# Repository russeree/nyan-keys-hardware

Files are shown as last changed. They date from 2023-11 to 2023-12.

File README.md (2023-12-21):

# Nyan Keys Hardware Docs v0.8a
Hardware documentation for the Nyan keys keyboard. Mixed licenses everything other than the board files are licensed under Apache-2.0 and board files are licensed under Attribution-NonCommercial-NoDerivatives. 

Made with ❤️ by Portland.HODL - If you like my work please submit PRs and or like/star my repos.

# Links to Firmware and FPGA Bitstream
Nyan Keys has 4 other repositories that go along with the hardware designs listed below
 - [FGPA Bitstream](https://github.com/russeree/nyan-keys-ice40hx4k-bitstream)
 - [STM32 Firmware](https://github.com/russeree/nyan-keys-stm32-firmware)
 - [Web Serial API GUI - hosted](https://russeree.github.io/)
 - [Web Serial API GUI - Source](https://github.com/russeree/nyan-keys-gui)

# Schematics
Schematics are provided as a .pdf file and will up to date with the latest release of Nyan keys hardware.

# Board Files
Board files are located under the board_files directory and were created in KiCad. These are licensed under
Creative Commons Attribution-NonCommercial-NoDerivatives license currently to prevent direct copying and 
manufacturing of the board files for commercial purposes.

Personal use is completely premised for this so if you want to make one for yourself or mod it feel free!

If you would like to avoid the logistics of acquiring the parts and getting a board made. I can fabricate and assemble boards on request. Please just email admin@qrsnap.io. 

# Board Revisions
| Board Version | Notes |
| --- | ----- |
| 0.8a | Prototypes 000, 001 **_USB DP/DM Error_** |
| 0.9a | Initial Release - USB Error Fixed|
| 0.9b | Added DFU Soft Select, All 0402, Tag Connect with clips |

# Layout
<div align="center">
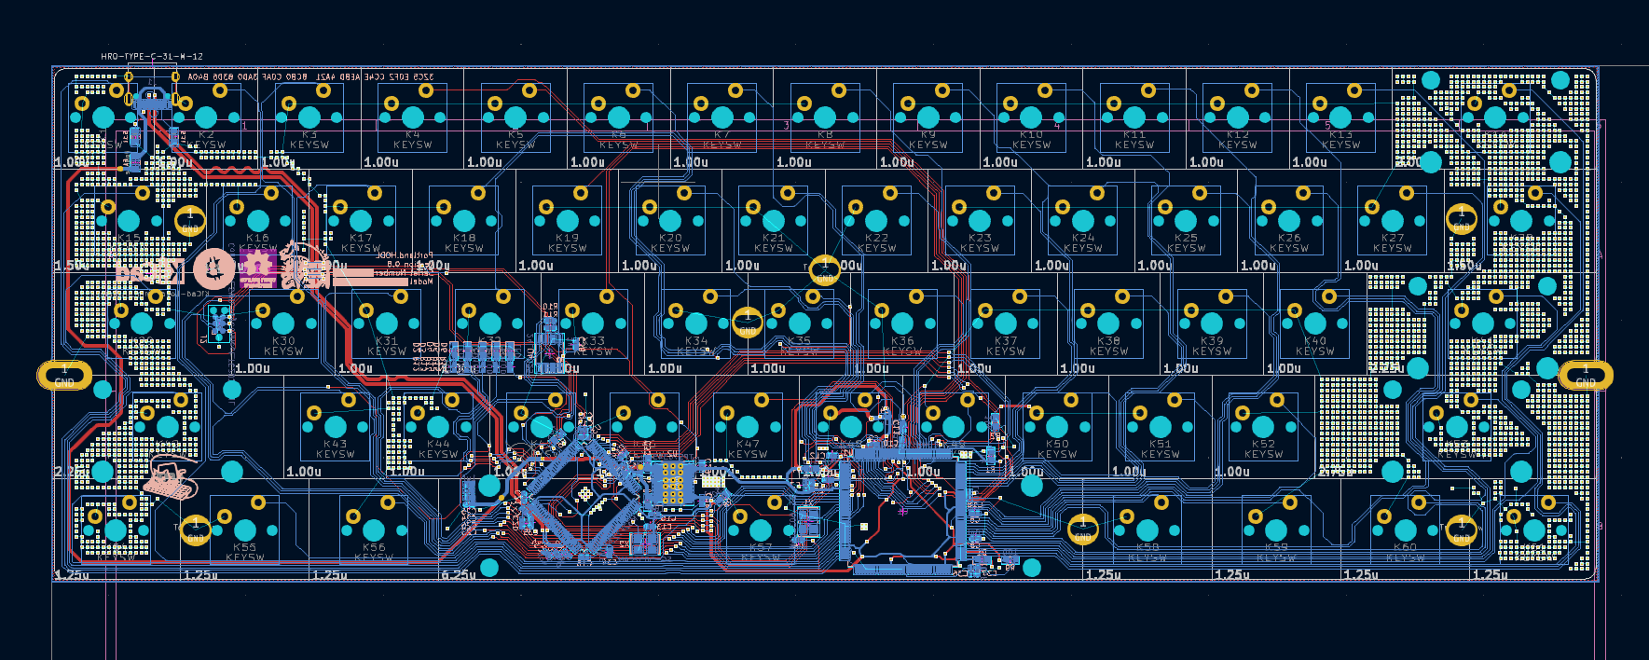
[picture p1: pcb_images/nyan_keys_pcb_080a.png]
    
</div>

<br>

# Finished Photos
<div align="center">
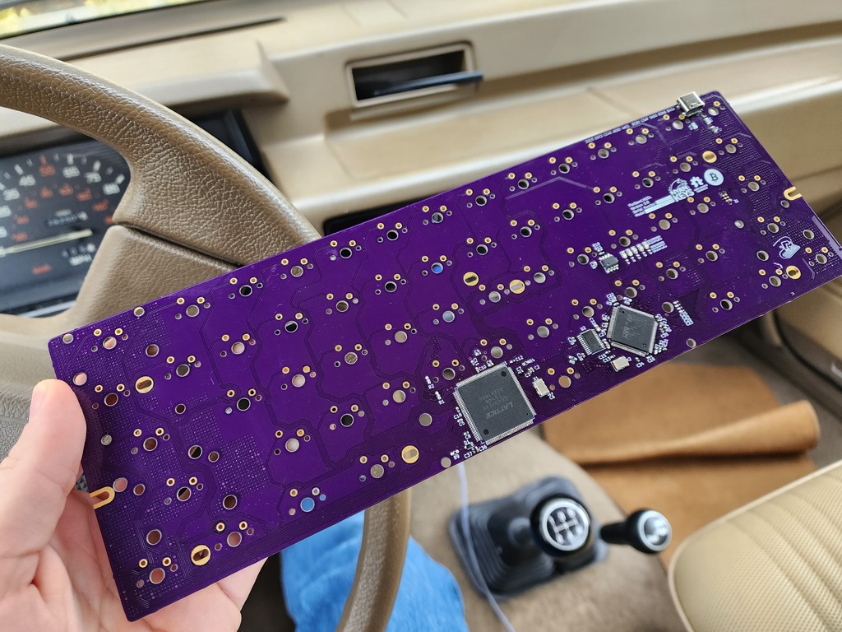
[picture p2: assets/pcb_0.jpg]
    
    <hr>
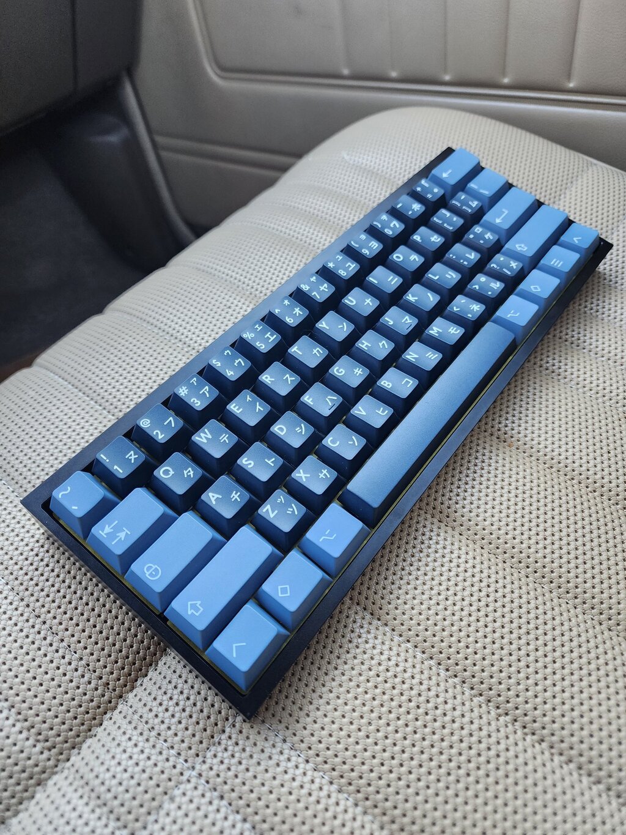
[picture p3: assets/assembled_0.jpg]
    
</div>

# Fabrication
<div align="center">
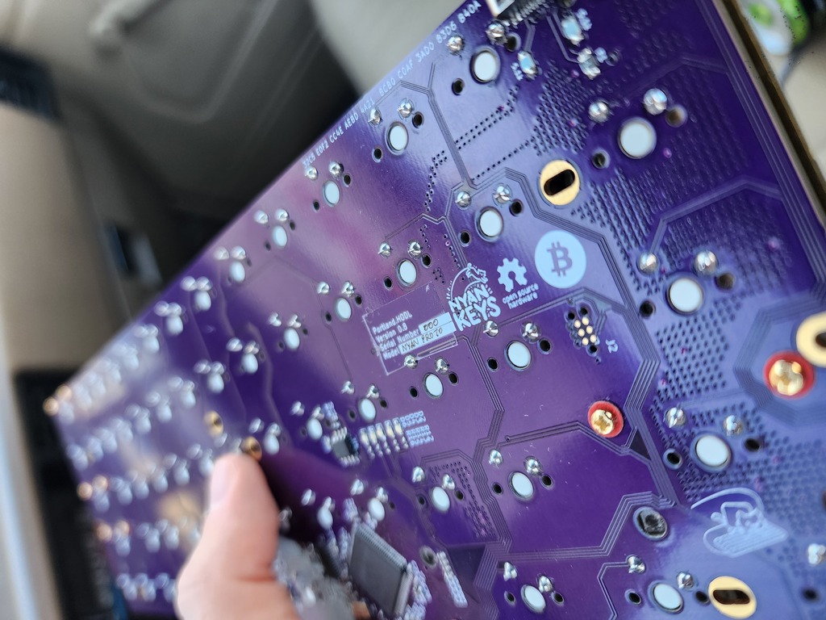
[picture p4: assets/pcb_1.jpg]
    
    <hr>
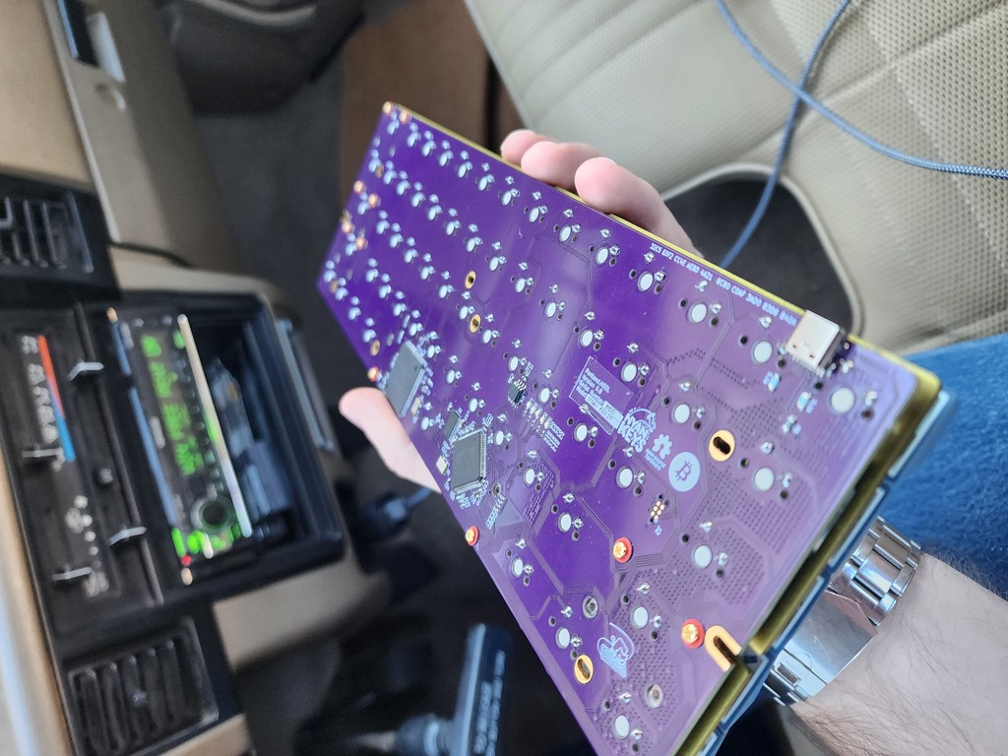
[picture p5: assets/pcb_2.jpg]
    
    <hr>
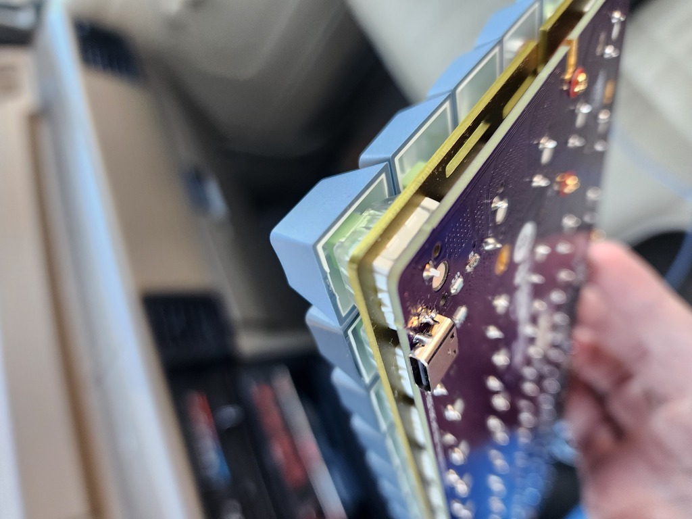
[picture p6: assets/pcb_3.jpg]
    
    <hr>
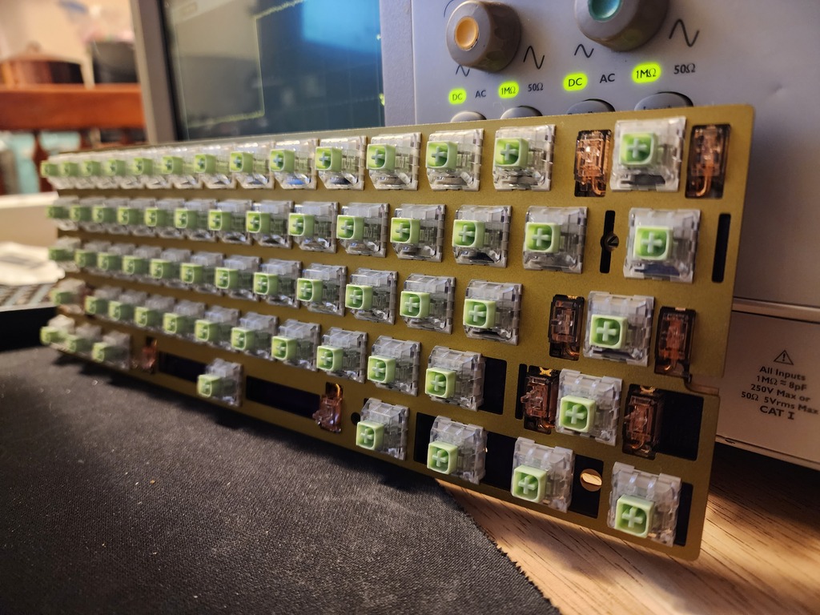
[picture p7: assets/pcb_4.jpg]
    
    <hr>
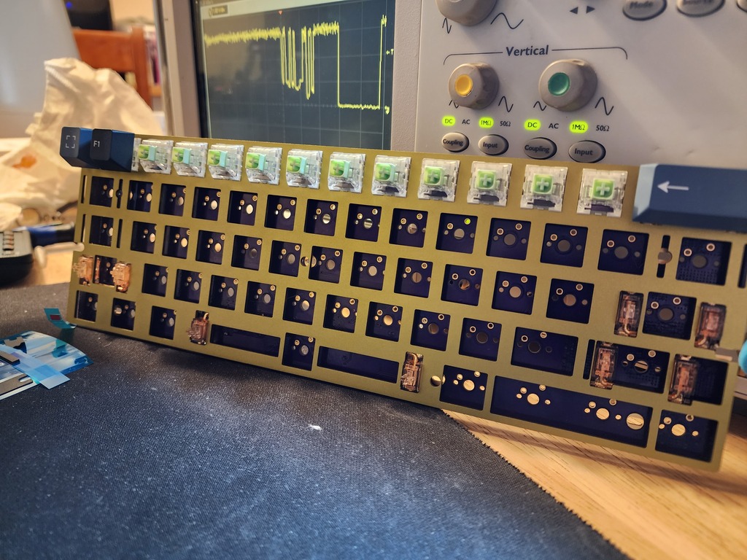
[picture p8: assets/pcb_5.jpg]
    
    <hr>
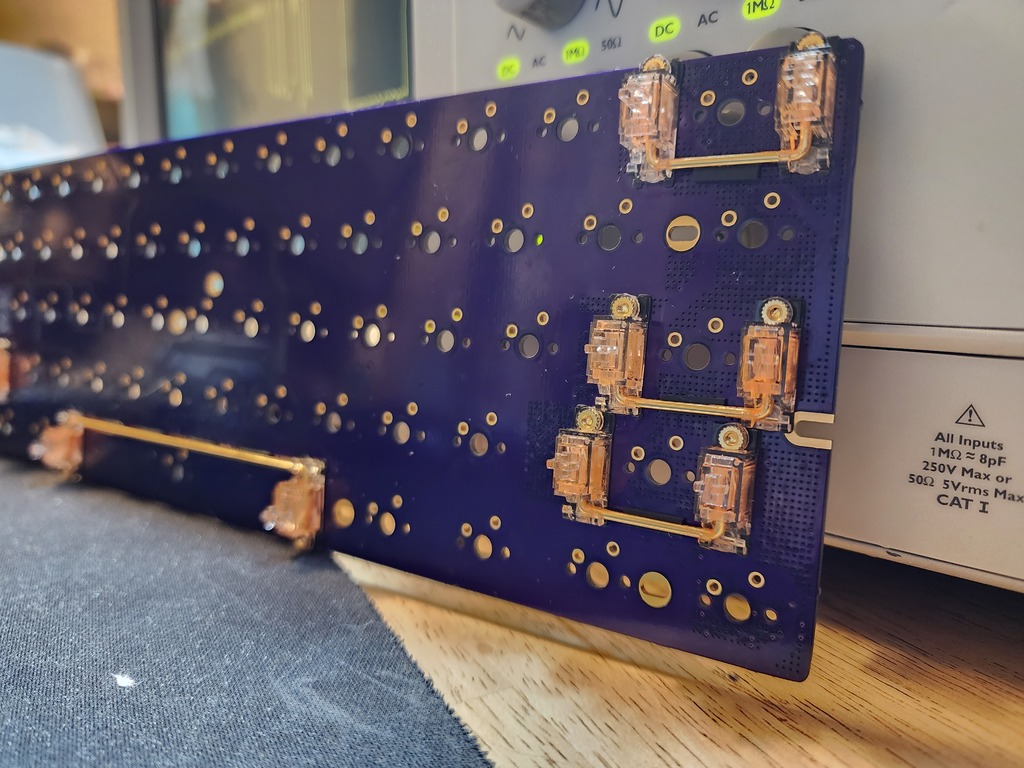
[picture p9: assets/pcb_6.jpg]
    
</div>

<br>

# Assembly
<div align="center">
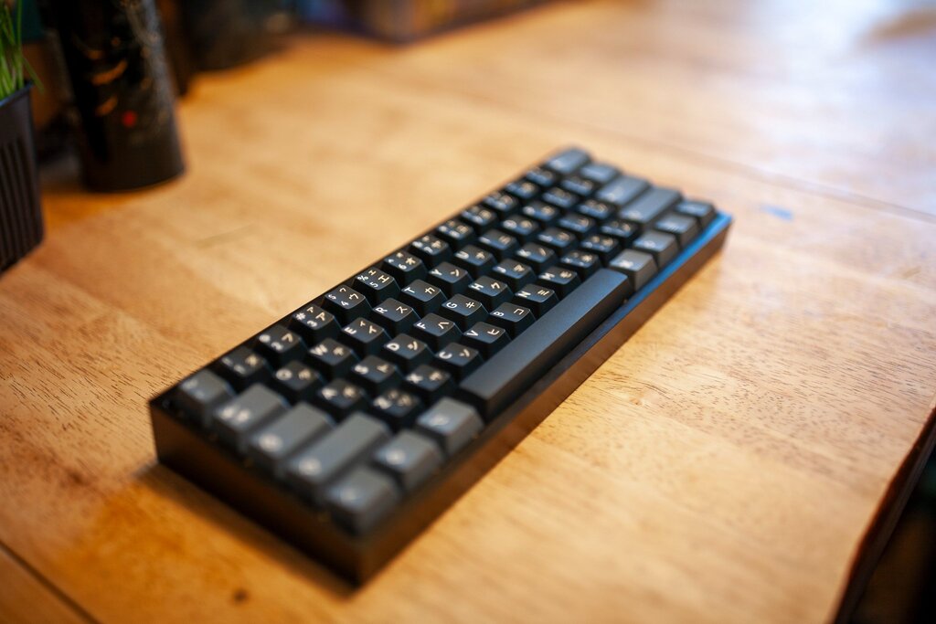
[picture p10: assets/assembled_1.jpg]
    
    <hr>
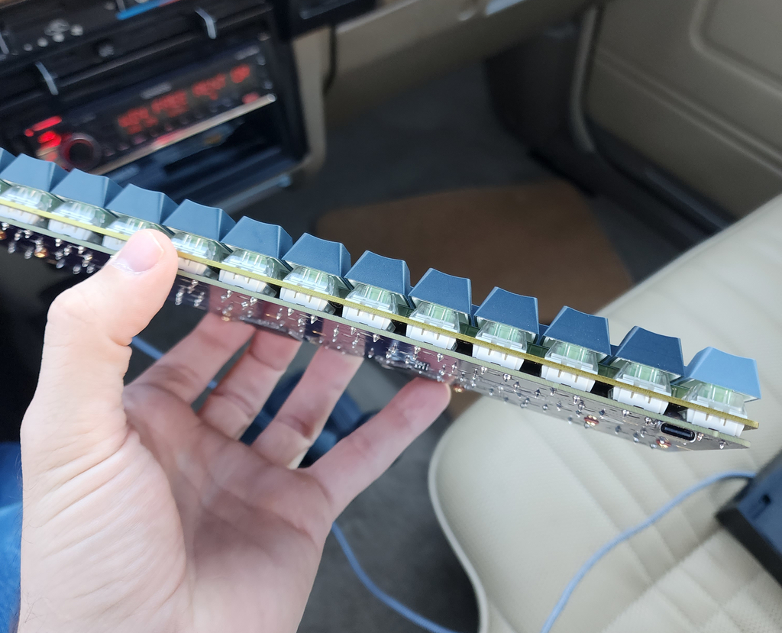
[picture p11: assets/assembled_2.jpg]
    
    <hr>
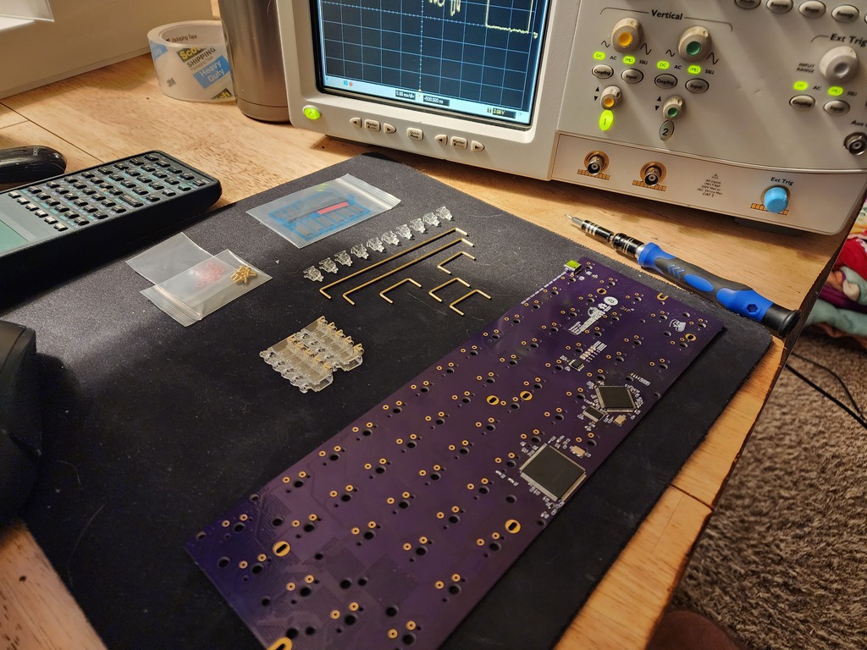
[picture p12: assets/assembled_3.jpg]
    
    <hr>
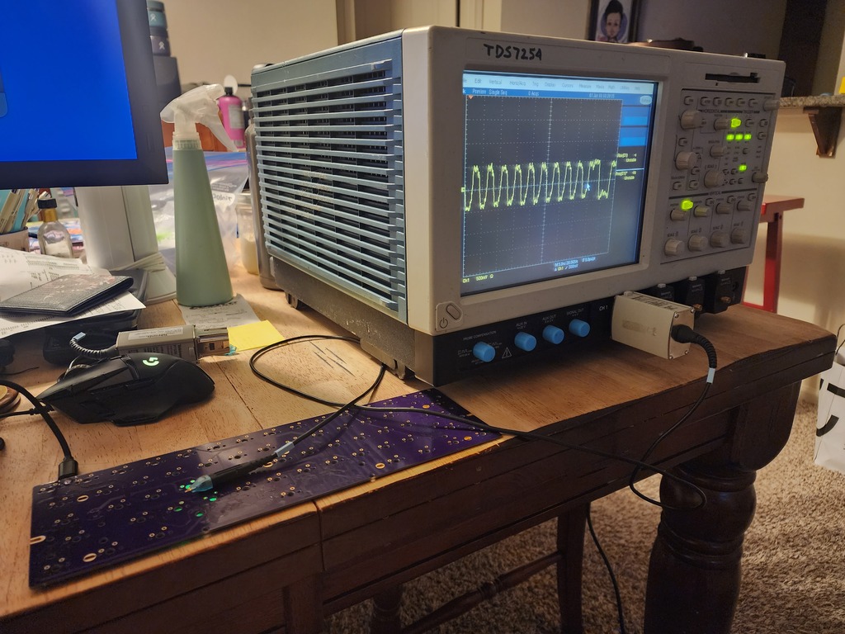
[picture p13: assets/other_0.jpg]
    
    <hr>
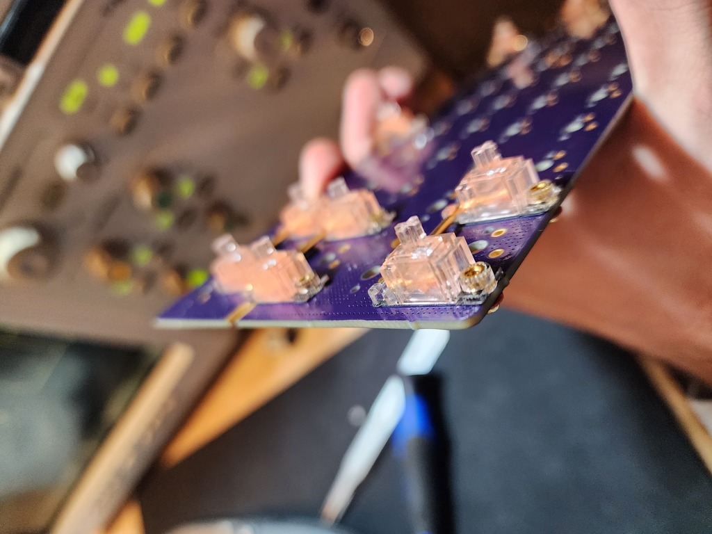
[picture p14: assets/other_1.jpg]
    
    <hr>
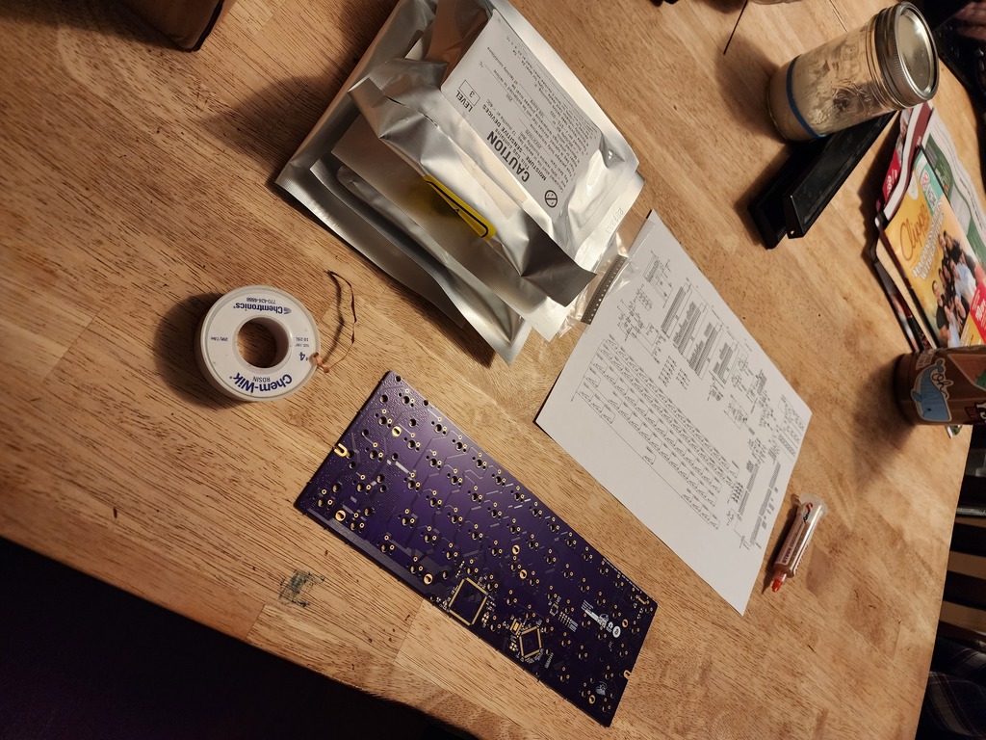
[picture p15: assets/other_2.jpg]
    
</div>

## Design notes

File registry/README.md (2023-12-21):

| Serial | Switches | Case | Caps | Stabs | Plate |
| --- | --- | --- | --- | --- | --- |
| 000 | Kailh Box Jade | Tofu Redux Black | PBTFans Spark V2 | Durock V2 Clear | Aluminum |
| 001 | Cherry MX2A Brown | Tofu Redux Mocha | PBTFans Bank Account | Durock V2 Teal | Brass |

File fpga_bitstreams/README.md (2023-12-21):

# PRODUCTION FPGA BITSTREAMS
This directory is for production ready FPGA bitstreams that have been tuned for for various switch types. If you are having trouble with key double pressing just use a 10ms debounce bitstream. Nyan keys uses eager debouncing so unless you can press and release a switch in less than the debounce time it wont matter at all.

You can flash these using the [Nyan-GUI](russeree.github.io) just click write bitstream, select the file, wait and you will see a sha256 hash of the data written when the process is complete.

#  ⚠️ Warning ⚠️
You are dealing with FPGA bitstreams, this dictates the way your keyboard will read keys as such flashing the wrong bitstream can make it incredibly hard to flash back a working one. If you flash a bitstream for the wrong switches then you can get random and very fast input. This can make it near impossible to go to the Nyan-GUI to flash a working bitstream. 

The only way right now to fix the worst case is to disable the FPGA Init in the nyan keys firmware and use an 
STM32F411 Discovery kit as an ST-LINK interface and flash a modified recovery firmware. Then you can get into the Nyan-GUI and flash the correct bitstream. Then you have to reflash Nyan Keys to reenable the FPGA.

Version 0.9b boards have a soft DFU enable that might be able to be used to avoid having to open up you Nyan Keys board.

# Switches -> Bitstream Files
| Switches | Bitstream File | Notes | 
| --- | --- | ----- |
| Kailh Box Jade | kailh_box_jade_Xms.bin | Datasheet Debounce 5ms Actual 3-4ms worst case |
| Cherry MX2A brown | cherry_mx2a_brown_10ms.bin | Datasheet Debounce ~1ms Actual 6-8ms worst case |

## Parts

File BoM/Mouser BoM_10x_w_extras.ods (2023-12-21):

Mouser #: | Mfr. #: | Desc.: | Customer # | Order Qty. | Ext. (USD) | Price (USD) | Status
842-ICE40HX4K-TQ144 | iCE40HX4K-TQ144 | FPGA - Field Programmable Gate Array FPGA - Field Programmable Gate Array iCE40HX 3520 LUTs 1.2V Ultra Low-Power | U1 | 10 | $9.97 | $9.97 | 10 Shipped
750-CDBU0130L-HF | CDBU0130L-HF | Schottky Diodes & Rectifiers Schottky Diodes & Rectifiers VR=30V, IO=100mA | D1 | 10 | $0.303 | $0.303 | 10 Shipped
595-TPS70345PWP | TPS70345PWP | LDO Voltage Regulators LDO Voltage Regulators Dual-Output LDO Voltage Regulator | U2 | 10 | $6.74 | $6.74 | 10 Shipped
511-STM32F723VET6 | STM32F723VET6 | ARM Microcontrollers - MCU ARM Microcontrollers - MCU High-performance & DSP FPU, Arm Cortex-M7 MCU 512 Kbytes of Flash 216 MHz CPU, A | U3 | 10 | $12.67 | $12.67 | 10 Shipped
732-SG5032CAN25TJGA0 | SG5032CAN 25.000000M-TJGA0 | Standard Clock Oscillators Standard Clock Oscillators SG5032CAN 25.000000M-TJGA0: SMD XTAL OSC ST 1.6-3.6V +/-50PPM -40-85C 1KTR | X2 | 10 | $0.697 | $0.697 | 10 Shipped
732-SG5032CAN12TJGA0 | SG5032CAN 12.000000M-TJGA0 | Standard Clock Oscillators Standard Clock Oscillators SG5032CAN 12.000000M-TJGA0: SMD XTAL OSC ST 1.6-3.6V +/-50PPM -40-85C 1KTR | X1 | 10 | $0.697 | $0.697 | 10 Shipped
579-24LC1025T-I/SN | 24LC1025T-I/SN | EEPROM EEPROM 1024K 128K X 8 2.5V |  | 10 | $3.81 | $3.81 | 10 Shipped
576-0805L200SLTHYR | 0805L200SLTHYR | Resettable Fuses - PPTC Resettable Fuses - PPTC 6V POLYFUSE 0805 LoRho SL 2.00A |  | 10 | $1.68 | $1.68 | 10 Shipped
710-150060GS75000 | 150060GS75000 | Standard LEDs - SMD Standard LEDs - SMD WL-SMCW SMDMono TpVw Waterclr 0603 Green |  | 50 | $0.142 | $0.142 | 50 Shipped
581-04024W226MAT2A | 04024W226MAT2A | Multilayer Ceramic Capacitors MLCC - SMD/SMT Multilayer Ceramic Capacitors MLCC - SMD/SMT NEW GLOBAL PN KGM05DS60G226MH 4V 22uF X6S 0402 20% | C28, C29 | 50 | $0.422 | $0.422 | 50 Shipped
755-ESR01MZPF3001 | ESR01MZPF3001 | Thick Film Resistors - SMD Thick Film Resistors - SMD | R7 | 12 | $0.11 | $0.11 | 12 Shipped
581-04026D105KAT4A | 04026D105KAT4A | Multilayer Ceramic Capacitors MLCC - SMD/SMT Multilayer Ceramic Capacitors MLCC - SMD/SMT NEW GLOBAL PN KGM05AR50J105KN 6.3V 1uF X5R 0402 10% |  | 200 | $0.026 | $0.026 | 200 Shipped
581-04025C103KAT4A | 04025C103KAT4A | Multilayer Ceramic Capacitors MLCC - SMD/SMT Multilayer Ceramic Capacitors MLCC - SMD/SMT NEW GLOBAL PN KGM05AR71H103KN 50V 0.01uF X7R 0402 10% |  | 100 | $0.041 | $0.041 | 100 Shipped
652-CR0402JW-392GLF | CR0402-JW-392GLF | Thick Film Resistors - SMD Thick Film Resistors - SMD 3.9K OHM 5% |  | 30 | $0.009 | $0.009 | 30 Shipped
652-CR0402AJW-101GAS | CR0402AJW-101GAS | Thick Film Resistors - SMD Thick Film Resistors - SMD ResA-AS 0402 100R 5% 63mW TC200 |  | 60 | $0.011 | $0.011 | 60 Shipped
652-CR0402JW-104GLF | CR0402-JW-104GLF | Thick Film Resistors - SMD Thick Film Resistors - SMD 100K OHM 5% |  | 100 | $0.004 | $0.004 | 100 Shipped
594-MCU08050D5101BP1 | MCU08050D5101BP100 | Thin Film Resistors - SMD Thin Film Resistors - SMD .05W 5.1Kohms 0.1% 0805 25ppm |  | 20 | $0.379 | $0.379 | 20 Shipped

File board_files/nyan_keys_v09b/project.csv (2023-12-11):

# | Reference | Qty | Value | Footprint | DNP
1 | C1, C2 | 2 | .1uF | Capacitor_SMD:C_0402_1005Metric_Pad0.74x0.62mm_HandSolder
2 | C3, C4, C5, C7, C8, C9, C10, C12, C14, C15, C16, C17, C18, C19, C20, C34, C35, C37 | 18 | 10uF | Capacitor_SMD:C_0402_1005Metric_Pad0.74x0.62mm_HandSolder
3 | C6, C11, C13, C23, C24, C25, C26, C31, C36 | 9 | 1uF | Capacitor_SMD:C_0402_1005Metric_Pad0.74x0.62mm_HandSolder
4 | C21, C22 | 2 | 10nF | Capacitor_SMD:C_0402_1005Metric_Pad0.74x0.62mm_HandSolder
5 | C27 | 1 | 4.7uF | Capacitor_SMD:C_0402_1005Metric_Pad0.74x0.62mm_HandSolder
6 | C28, C29 | 2 | 22uF | Capacitor_SMD:C_0402_1005Metric_Pad0.74x0.62mm_HandSolder
7 | C30, C33 | 2 | 22uF | Capacitor_SMD:C_0603_1608Metric_Pad1.08x0.95mm_HandSolder
8 | C32 | 1 | 0.1nF | Capacitor_SMD:C_0402_1005Metric_Pad0.74x0.62mm_HandSolder
9 | D1 | 1 | D | Diode_SMD:D_0603_1608Metric_Pad1.05x0.95mm_HandSolder
10 | F1 | 1 | Polyfuse | Keeb_components:R_0805
11 | J1 | 1 | HRO-TYPE-C-31-M-12 | Keeb_components:HRO-TYPE-C-31-M-12
12 | K1, K2, K3, K4, K5, K6, K7, K8, K9, K10, K11, K12, K13, K16, K17, K18, K19, K20, K21, K22, K23, K24, K25, K26, K27, K30, K31, K32, K33, K34, K35, K36, K37, K38, K39, K40, K43, K44, K45, K46, K47, K48, K49, K50, K51, K52 | 46 | KEYSW | Keeb_switches:CHERRY_PLATE_100H
13 | K14 | 1 | KEYSW | Keeb_switches:CHERRY_PCB_200H
14 | K15, K28 | 2 | KEYSW | Keeb_switches:CHERRY_PLATE_150H
15 | K29 | 1 | KEYSW | Keeb_switches:CHERRY_PLATE_175H
16 | K41, K42 | 2 | KEYSW | Keeb_switches:CHERRY_PCB_225H
17 | K53 | 1 | KEYSW | Keeb_switches:CHERRY_PCB_275H
18 | K54, K55, K56, K58, K59, K60, K61 | 7 | KEYSW | Keeb_switches:CHERRY_PLATE_125H
19 | K57 | 1 | KEYSW | Keeb_switches:CHERRY_PCB_625H_F
20 | R1, R2, R6 | 3 | 10k | Resistor_SMD:R_0603_1608Metric_Pad0.98x0.95mm_HandSolder
21 | R3, R5 | 2 | 5.1k | Keeb_components:R_0805
22 | R4, R9 | 2 | 100 | Resistor_SMD:R_0603_1608Metric_Pad0.98x0.95mm_HandSolder
23 | R7 | 1 | 3k | Resistor_SMD:R_0402_1005Metric_Pad0.72x0.64mm_HandSolder
24 | R8 | 1 | 250k | Resistor_SMD:R_0603_1608Metric_Pad0.98x0.95mm_HandSolder
25 | S1, S3, S5, S9 | 4 | Screw | footprints:5.5_5x2.5mm
26 | S2, S4, S6 | 3 | Tofu screw | footprints:5.5_5x2.5mm
27 | S7, S8 | 2 | Screw | footprints:10x5_7x2.5mm
28 | U1 | 1 | ICE40HX4K-TQ144 | Package_QFP:TQFP-144_20x20mm_P0.5mm
29 | U2 | 1 | TPS70345 | Package_SO:HTSSOP-24-1EP_4.4x7.8mm_P0.65mm_EP3.4x7.8mm_Mask2.4x4.68mm_ThermalVias
30 | U3 | 1 | STM32F723VETx | Package_QFP:LQFP-100_14x14mm_P0.5mm
31 | X1, X2 | 2 | SG-5032CAN | Oscillator:Oscillator_SMD_SeikoEpson_SG8002LB-4Pin_5.0x3.2mm

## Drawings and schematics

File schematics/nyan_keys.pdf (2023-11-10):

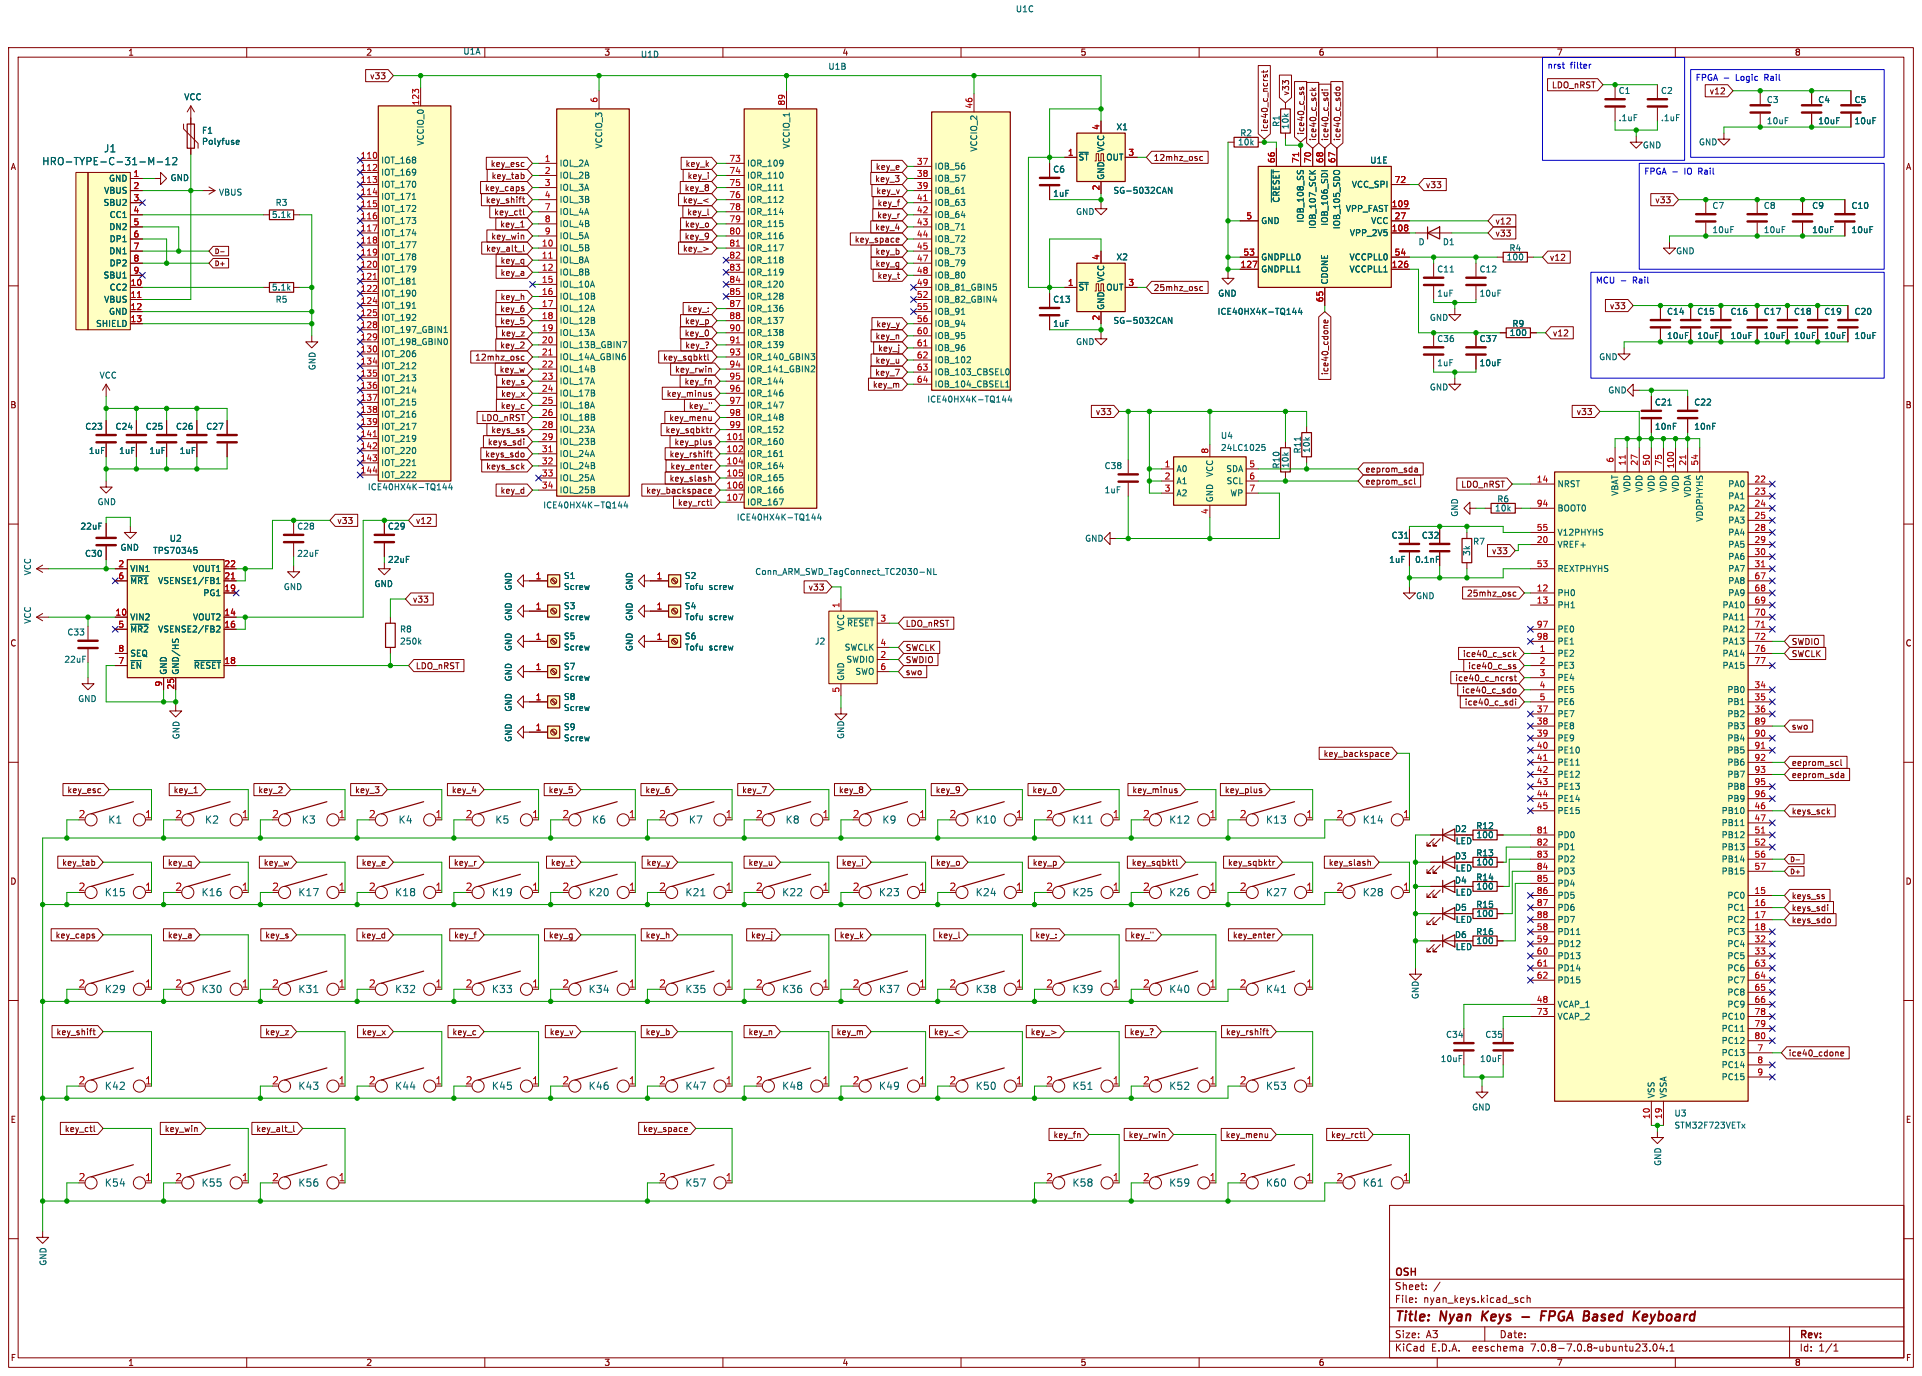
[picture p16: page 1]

4 SDA 5 SCL 6 WP 7 VCC

1 SWDIO 2 ~{RESET}3 SWCLK 4 GND

Id: 1/1 Title: Nyan Keys - FPGA Based Keyboard

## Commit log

2023-11-10 Add nyan keys schematic
    Added the nyan keys keyboard schematic
2023-11-29 Added image of PCB
2023-11-29 Image of PCB 0.8a
2023-11-30 switch image order for asthetics
2023-11-30 switch image order for asthetics - pt. 2
2023-11-30 switch image order for asthetics - pt. 3
2023-11-30 switch image order for asthetics - pt. 4
2023-11-30 switch image order for asthetics - pt. 6
2023-11-30 switch image order for asthetics - pt. 7
2023-11-30 switch image order for asthetics - pt. 8
2023-11-30 switch image order for asthetics - pt. 9
2023-12-11 Added board files under CC BY-NC-ND
2023-12-11 Add board files under CC BY-NC-ND
    [nyan_keys.csv, nyan_keys.kicad_sch]
2023-12-11 Added board files license update
2023-12-11 Add memo that I can create and assemble boards.
2023-12-21 add v0.9b board rev. all 0402, boot0 soft activate
    [Mouser BoM_10x_w_extras.ods]
2023-12-21 board rev 0.9b - boot0 soft activate, 0402
    [project.csv, project.kicad_sch]
2024-02-06 R7 patch
    [project.kicad_sch]
